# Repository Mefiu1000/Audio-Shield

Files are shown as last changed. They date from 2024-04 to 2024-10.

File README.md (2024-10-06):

# Audio shield

The project is an audio shield for STM32 nucleo board or any other board compatible with arduino uno connectors. The board is generating analog audio signal in bandwidth up to 10 kHz. Sound output can be switched between headphones (mono) or speaker. Additionally keyboard with 8 switches is added to program special sounds etc. to generate.

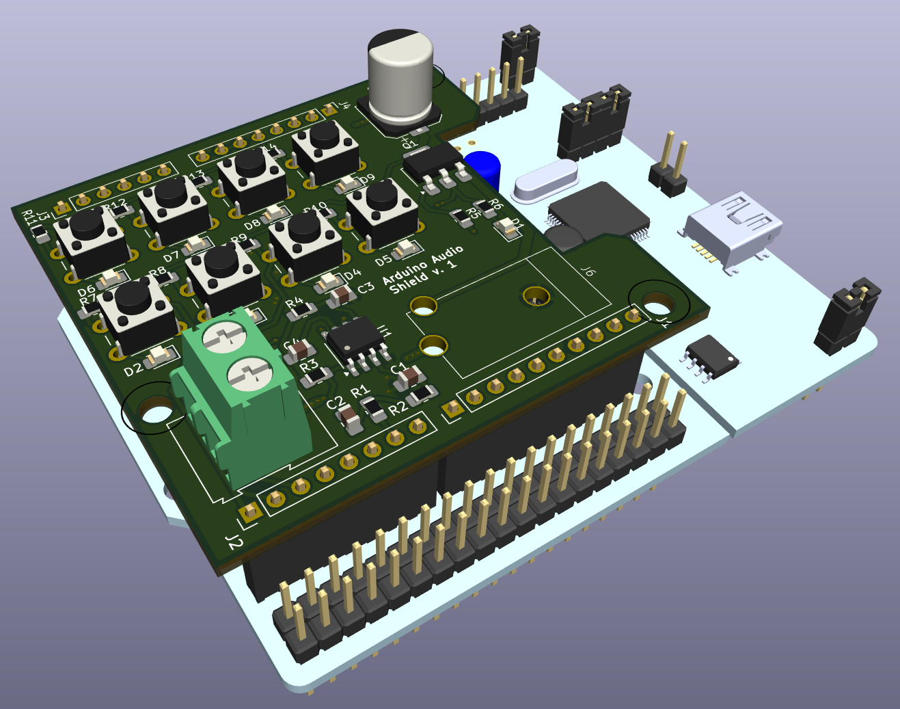
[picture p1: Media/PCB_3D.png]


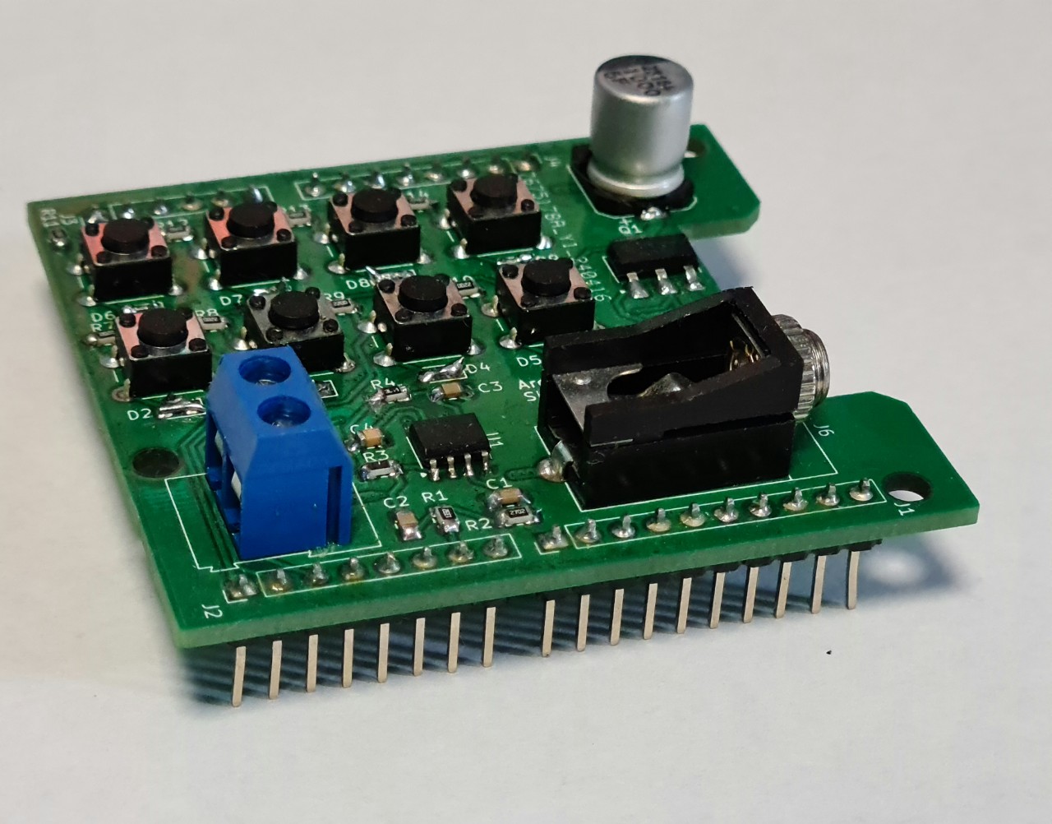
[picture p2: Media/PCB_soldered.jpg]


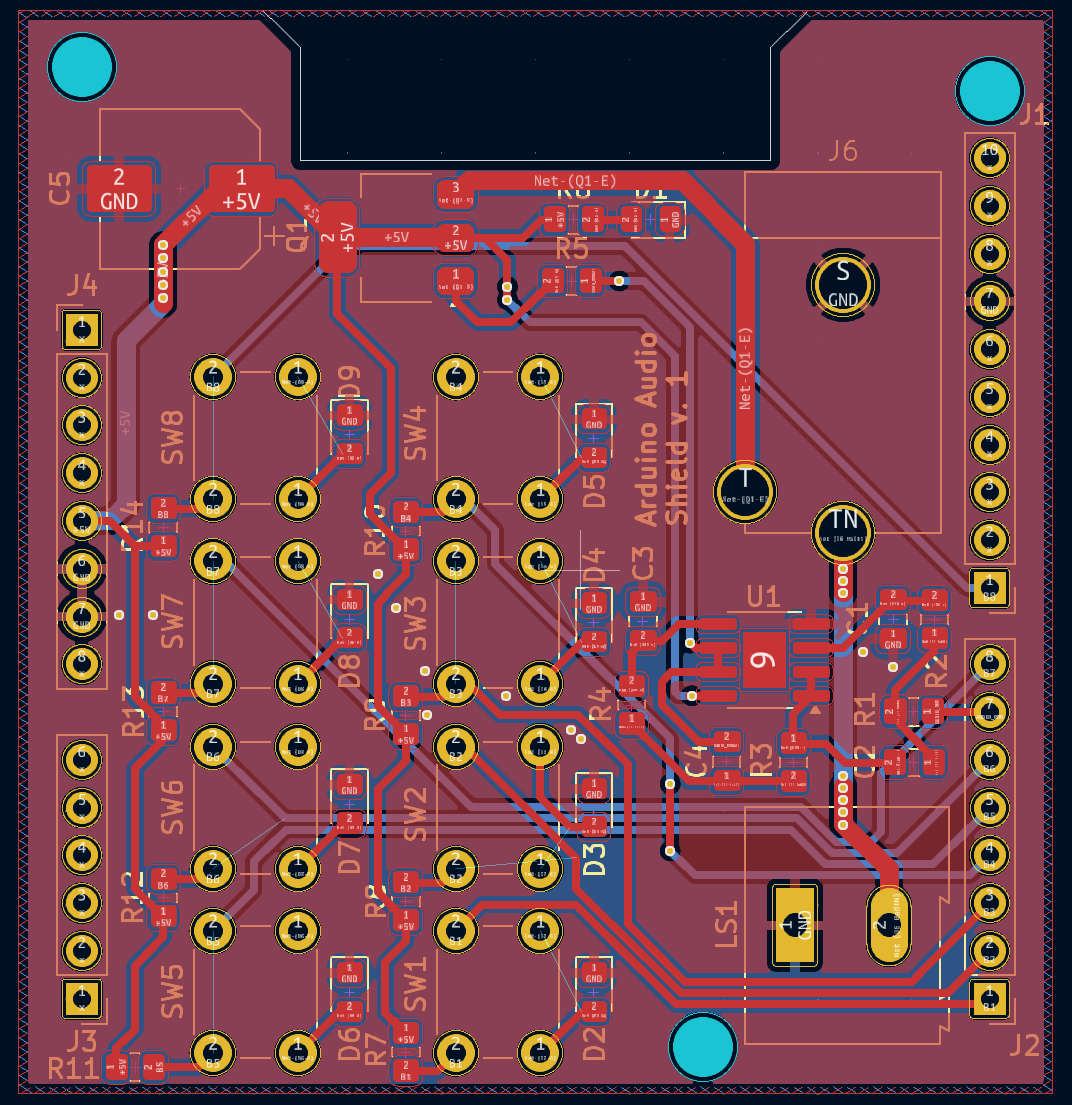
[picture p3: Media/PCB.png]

## RC filter

To amplify a signal in desired bandwidth, a 4th order lowpass Chebyshev filter was used, because of its step roll-off characteristics. Filter was designed with a use of Texas Instruments Filter Design Tool:
https://webench.ti.com/filter-design-tool/filter-type

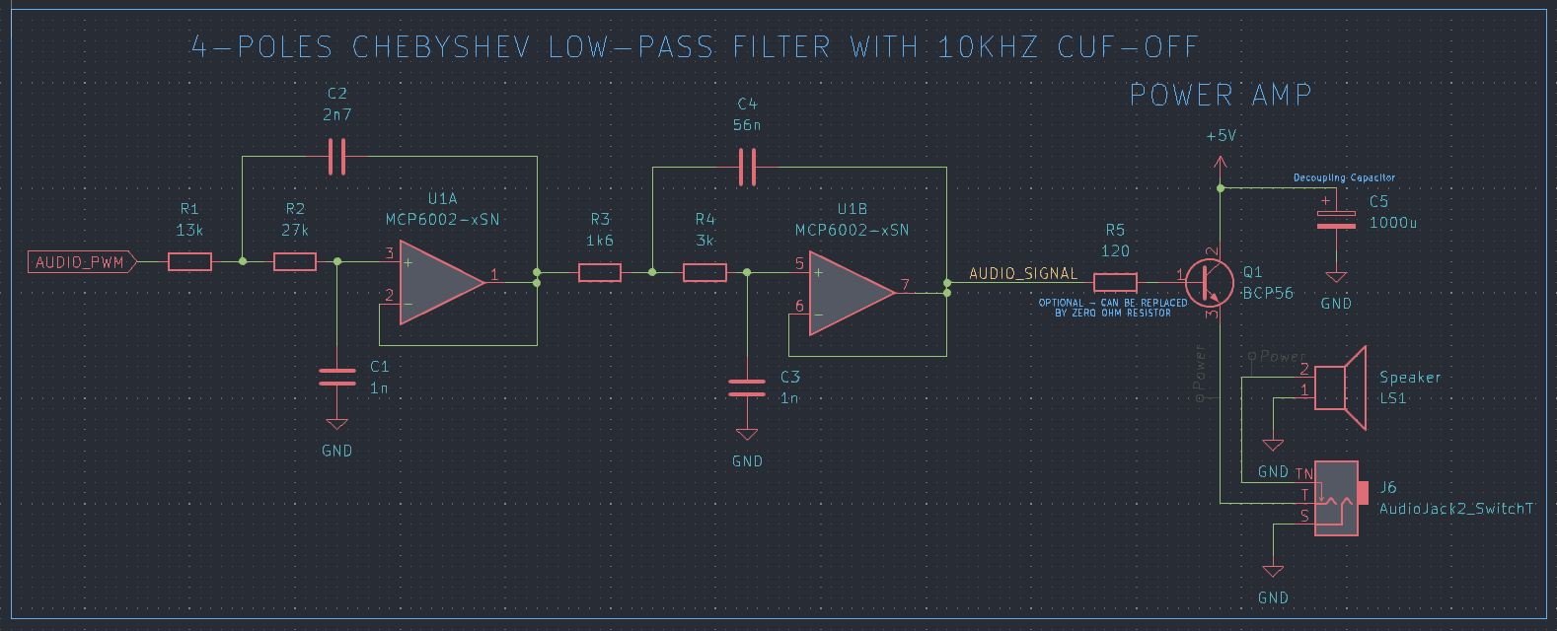
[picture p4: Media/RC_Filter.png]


## Software

- KiCad v.8.0

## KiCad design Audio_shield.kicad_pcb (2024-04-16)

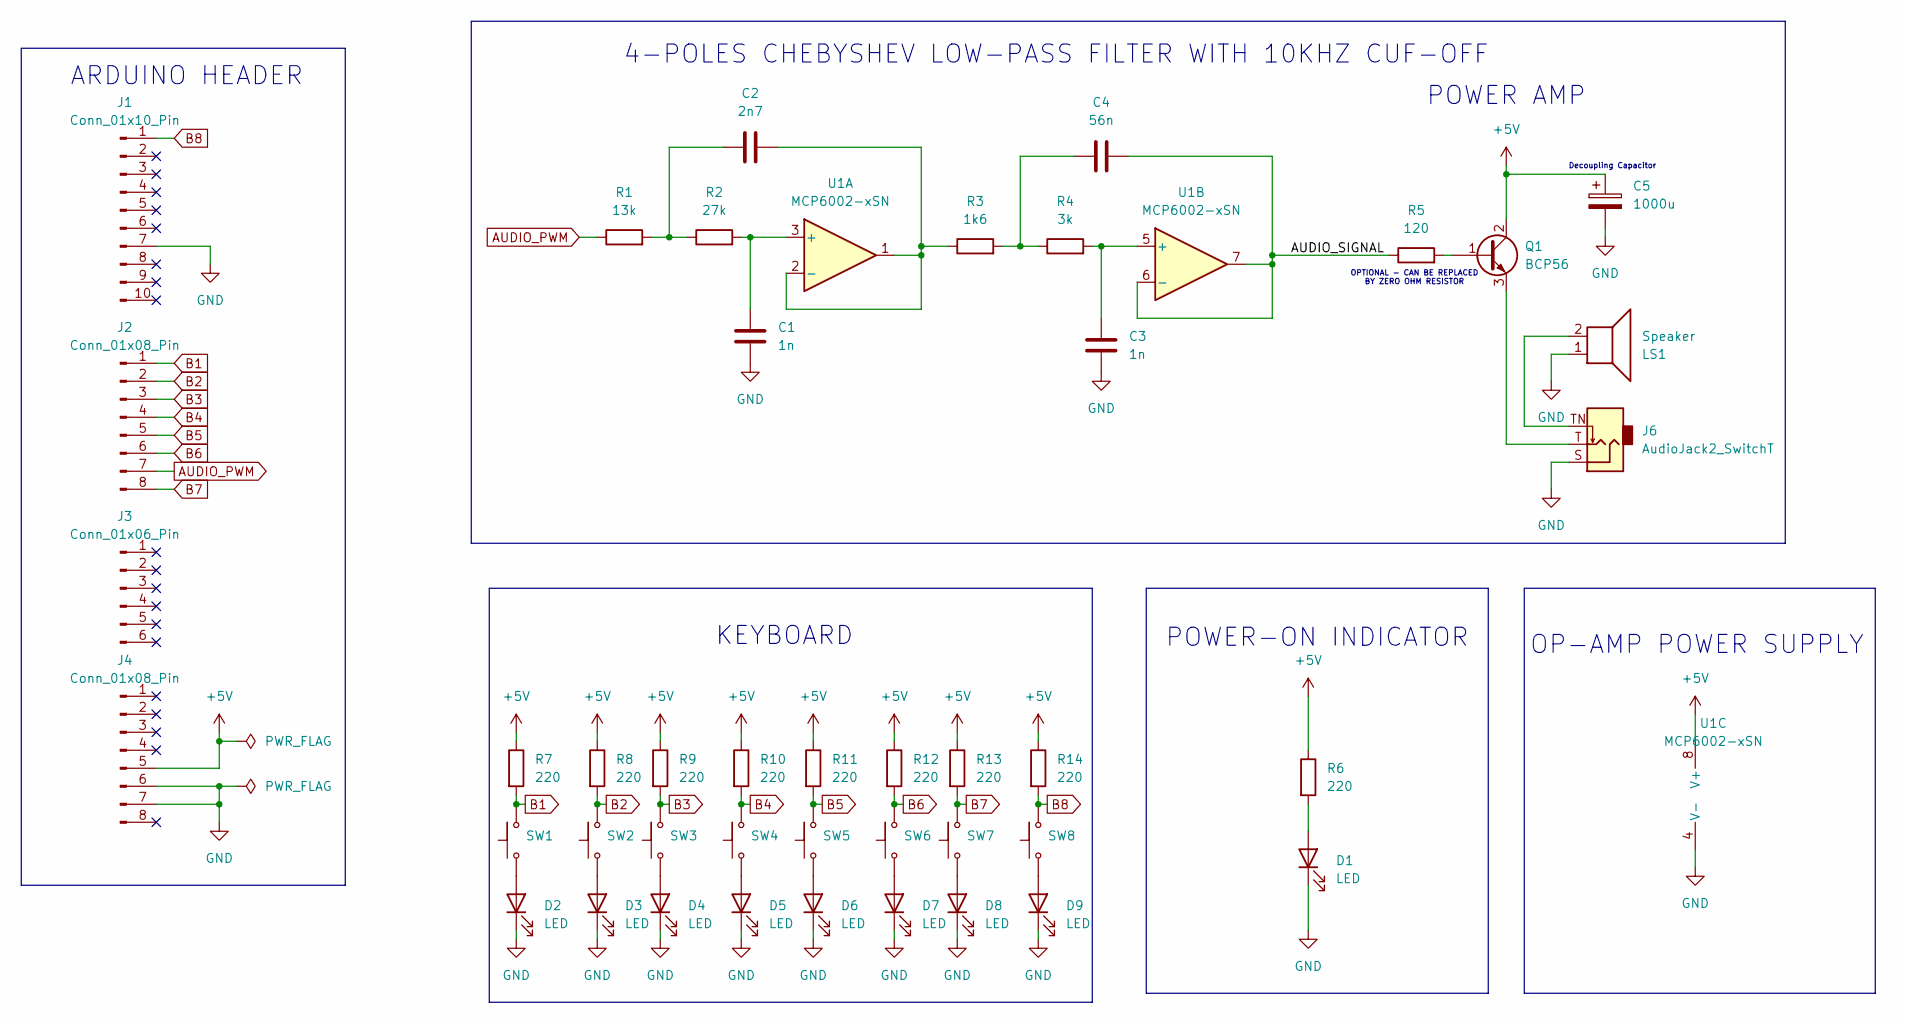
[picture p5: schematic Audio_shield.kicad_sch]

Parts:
C1, C3: 1n; C_0805_2012Metric_Pad1.18x1.45mm_HandSolder
C2: 2n7; C_0805_2012Metric_Pad1.18x1.45mm_HandSolder
C4: 56n; C_0805_2012Metric_Pad1.18x1.45mm_HandSolder
C5: 1000u; CP_Elec_8x10
D1, D2, D3, D4, D5, D6, D7, D8, D9: LED; LED_0805_2012Metric_Pad1.15x1.40mm_HandSolder
J1: Conn_01x10_Pin; PinHeader_1x10_P2.54mm_Vertical
J2, J4: Conn_01x08_Pin; PinHeader_1x08_P2.54mm_Vertical
J3: Conn_01x06_Pin; PinHeader_1x06_P2.54mm_Vertical
J6: AudioJack2_SwitchT; Jack_3.5mm_Cliff_FC68118_Horizontal
LS1: Speaker; TerminalBlock_Altech_AK300-2_P5.00mm
Q1: BCP56; SOT-223-3_TabPin2
R1: 13k; R_0805_2012Metric_Pad1.20x1.40mm_HandSolder
R2: 27k; R_0805_2012Metric_Pad1.20x1.40mm_HandSolder
R3: 1k6; R_0805_2012Metric_Pad1.20x1.40mm_HandSolder
R4: 3k; R_0805_2012Metric_Pad1.20x1.40mm_HandSolder
R5: 120; R_0805_2012Metric_Pad1.20x1.40mm_HandSolder
R6, R7, R8, R9, R10, R11, R12, R13, R14: 220; R_0805_2012Metric_Pad1.20x1.40mm_HandSolder
SW1, SW2, SW3, SW4, SW5, SW6, SW7, SW8: SW_PUSH_6mm_H5mm
U1: MCP6002-xSN; SOIC-8-1EP_3.9x4.9mm_P1.27mm_EP2.29x3mm

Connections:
+5V: C5.1, J4.5, Q1.2 (C), R6.1, R7.1, R8.1, R9.1, R10.1, R11.1, R12.1, R13.1, R14.1, U1.8 (V+)
/AUDIO_SIGNAL: C4.2, R5.1, U1.6 (-), U1.7
AUDIO_PWM: J2.7, R1.1
B1: J2.1, R7.2, SW1.2 (B)
B2: J2.2, R8.2, SW2.2 (B)
B3: J2.3, R9.2, SW3.2 (B)
B4: J2.4, R10.2, SW4.2 (B)
B5: J2.5, R11.2, SW5.2 (B)
B6: J2.6, R12.2, SW6.2 (B)
B7: J2.8, R13.2, SW7.2 (B)
B8: J1.1, R14.2, SW8.2 (B)
GND: C1.1, C3.1, C5.2, D1.1 (K), D2.1 (K), D3.1 (K), D4.1 (K), D5.1 (K), D6.1 (K), D7.1 (K), D8.1 (K), D9.1 (K), J1.7, J4.6, J4.7, J6.S, LS1.1, U1.4 (V-)
unnamed: C2.1, R1.2, R2.1
unnamed: C4.1, R3.2, R4.1
unnamed: D1.2 (A), R6.2
unnamed: D2.2 (A), SW1.1 (A)
unnamed: D3.2 (A), SW2.1 (A)
unnamed: D4.2 (A), SW3.1 (A)
unnamed: D5.2 (A), SW4.1 (A)
unnamed: D6.2 (A), SW5.1 (A)
unnamed: D7.2 (A), SW6.1 (A)
unnamed: D8.2 (A), SW7.1 (A)
unnamed: D9.2 (A), SW8.1 (A)
unnamed: J6.TN, LS1.2
unnamed: Q1.1 (B), R5.2
unnamed: J6.T, Q1.3 (E)
unnamed: C1.2, R2.2, U1.3 (+)
unnamed: C2.2, R3.1, U1.1, U1.2 (-)
unnamed: C3.2, R4.2, U1.5 (+)

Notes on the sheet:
4-POLES CHEBYSHEV LOW-PASS FILTER WITH 10KHZ CUF-OFF
OP-AMP POWER SUPPLY
Decoupling Capacitor
POWER AMP
OPTIONAL - CAN BE REPLACED BY ZERO OHM RESISTOR
ARDUINO HEADER
KEYBOARD
POWER-ON INDICATOR

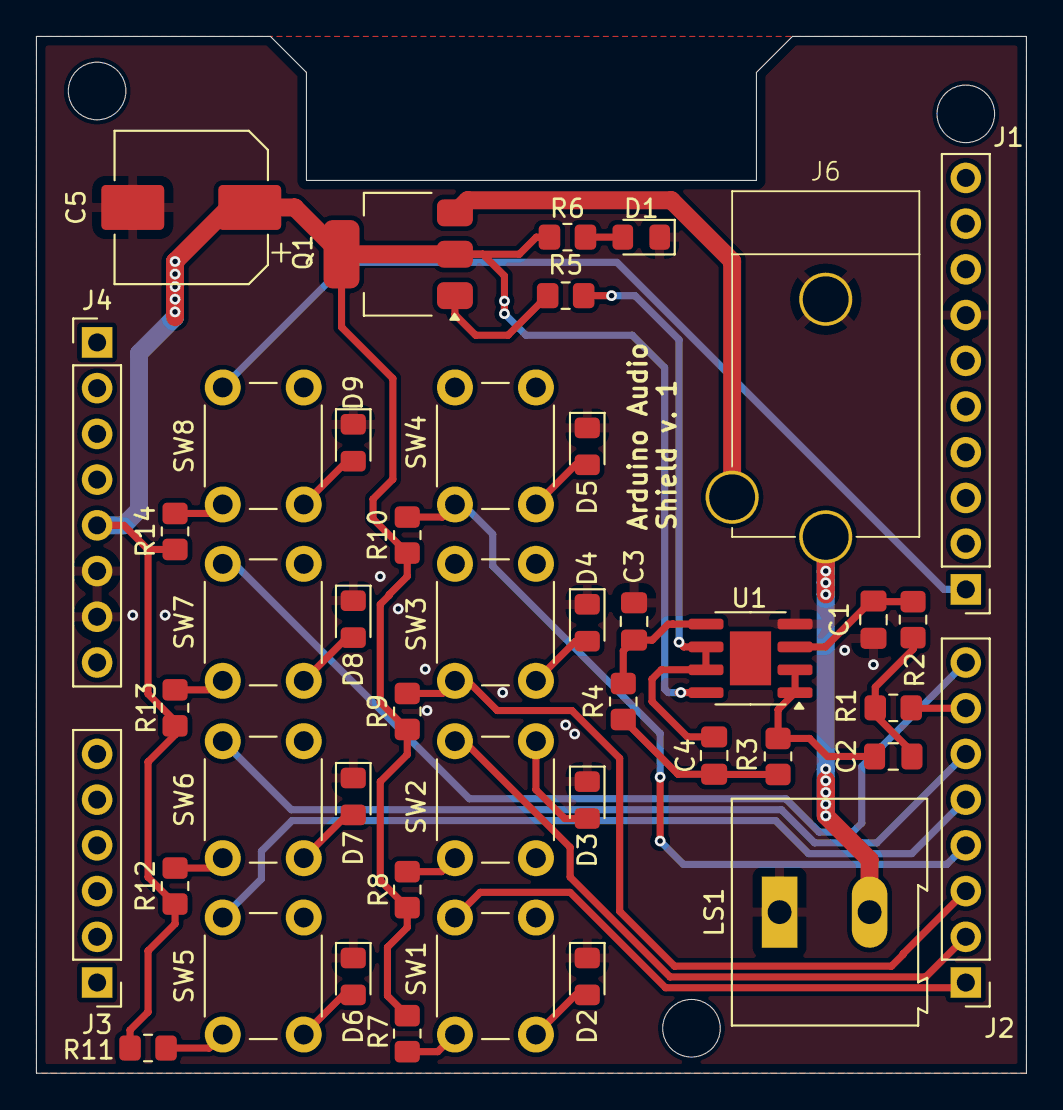
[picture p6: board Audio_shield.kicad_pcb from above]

Board: 2 copper layers, 55.0 x 57.6 mm, 44 parts (0 on the bottom side), 29 nets.
